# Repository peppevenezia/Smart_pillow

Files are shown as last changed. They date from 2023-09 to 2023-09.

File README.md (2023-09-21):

# Posture Monitoring System - PsoCuscino

This project was developed in collaboration with https://github.com/giovanni6inve , https://github.com/Sebastian-Gerletti , https://github.com/alecac96

## Aim of the project

Sitting posture classifiaction for behavioral analysis of desk workers, in particuar working at PC. Data is collected from 11 FSR sensors (Force Sensitive Resistors) arranged on a chair.

## Hardware and set-up
<figure>

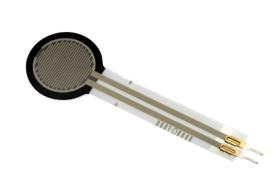
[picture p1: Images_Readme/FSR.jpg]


<figcaption>Force Sensitive Resistor (FSR).</figcaption>

</figure>

FSR sensors (strain gauges) are read by voltage partitioning on a resistance of 10kohm (Rb) and high impedence readout provided by the PSoC.

<figure>

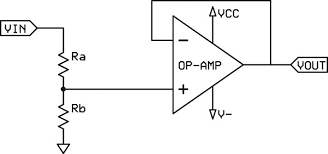
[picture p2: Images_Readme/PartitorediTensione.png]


<figcaption>Vin is 5V alimentation, the variable resistance (FSR) is Ra.</figcaption>

</figure>

The 11 sensors are iteratively read by an AMUX which feeds the analog signal for conversion to the ADC DelSig configured at 16 bit resolution, Multi Sample (since independent sensors) and 10000SPS. The sampling period is of 300ms, set by timer ISR, at which all sensors are read, sampled and sent to the GUI using UART serial communication (baud rate of 115200bps).

For easy and simple interfacing with the user (namely connection research, connected, sampling and calibration) a LED was set using a variable PWM. 

The sensor disposition upon the chair is symmetric w.r.t. the sagittal plane and while maintaining a base disposition as in figure, their precise position was optimized for maximum activation according to physiological pressure points and allowing for interuser variability: namely male/female, height ranges from 154cm to 200cm and weights from 49kg to 93kg.

<figure>

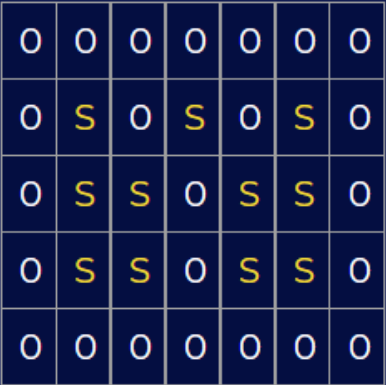
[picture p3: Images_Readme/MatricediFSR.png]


<figcaption>Where "S" stands for the FSR sensor and 0 is for the space on the hard surface, where they are attached to with tape, in between them.</figcaption>

</figure>

## Firmware (PSoC)

Connection between GUI and PSoC is dealt with automatically: the GUI sends "v" by UART, PSoC transmits "Posture$$$" in responce; if this "handshaking" (mutual recognition happens) connecion is confirmed by the GUI: "e" is received.

Once "b" is received all sensors are sampled at 3.33Hz and the 16bit value for each one is unpacked into 2 bytes for serial communication. During the first 4.5s, during which the subject is already seated, the calibration procedure takes place: it is aimed at rescaling all sensors' values by the same factor in order to exploit the whole 16 bit range, the factor is obtained dividing the desired maximum output (65535) by the actual global maximum among the sampled values for all sensors (15 samples * 11 sensors). By doing so a heavy subject and a lighter one will be associated with an equally intense heatmap (considering the values for the higher pressure points).

The synchrony and activation of all this is given by the a timer which is turned on upon "b" receval and off with "s".

## Software (GUI)
(Particular attention was given to interoperability of the whole process among different operating systems).

Upon launching the application, in order to find the port to which the PSoC is connected to, all the list of ports is iterated and the char "v" is sent to each port with a hardcoded baud rate (shared by the PSoC). Ports are passed by if a limit of time spent within them is reached; if "Posture$$$" is received connection is confirmed with that port (PSoC's one) by sending "e" to it.

To then communicate with the device a user-friendly interface is presented: "start" and "stop" buttons, which transmit "b" and "s" respectively; as for visualization, once "start" has been pressed the heatmap given by the sensors' padded and interpolated (upsampled) data is presented; and below the heatmap the posture prediction is written having as classes: "correct", "leaning forwards", "leaning backwards", "leaning right" and "leaning left". Notice the sensors' set-up, should also guarantee the recognition of crossed-legs posture but in order to train a network capable to distinguish between leaning sideways and doing so with crossed legs much more data would have been necessary to obtain satisfying performances since a more complex model would have been necessary to face the more complex task.
#### Data decoding
Each sensor value is kept in 16 bit format, so the heatmap scale goes from 0 to 65535; however since a string of 48 chars containing all sensors' data scopmosed in MSB and LSB (each then composed by 2 chars) is received, the 11 sensors values need to be re-assembled (reverse the shift and masking done at PSoC level) after cropping the head and the tail (each of 2 fixed chars).
#### Interpolation (upsampling)
Plotting only the 11 values which are sampled from the sensors is not sufficient for a clear and interpretable image, for this reason upsampling is required, the best method to replicte true weight distribution proved to be interpolation done using scipy's griddata function and an appropriate padding.

Padding is done, by linealy combining the sensors' values according to the matrix in the figure above and accounting for borders using a multiplicative decay. This was done to space the sensors' positions both from borders and from each other when feeding them to griddata which then performs a much more complex interpolation accounting for the exact positions of sensors (measured on the chair) and custom padding  (approximated from the previous measurements) and exploiting a non linear combination of values. A 41x45 image is thus obtained.

<figure>

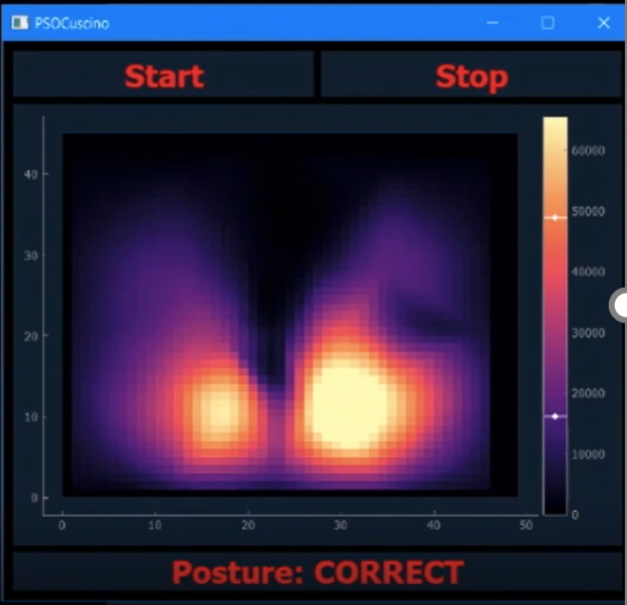
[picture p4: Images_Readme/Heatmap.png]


<figcaption>GUI: buttons, heatmap, class prediction.</figcaption>

</figure>

#### Posture classification
To classify the posture among the aforementioned classes a neural network was implemented. A prediction is provided for each frame (300ms) by inserting the prediction "pipeline" within the iterating thread of the GUI which reads, interpolates and plots data. The pipeling includes data rescaling other than the actual prediction and it does so by using the parameters obtained from the training set to normalize the data and the saved model.

The model to classify each frame is a neural network which was trained,tuned and tested with data from 15 users, split in 2 disjoint and stratified sets (after informed consent signing).

The protocol to acquire the training data, and quite intuitively to label it, was to sample 1min (so 200 samples per position) in each position (after calibration) in the same order reported above.

Notice: for the model training a few considerations must be made regarding the replicability of our procedure:\
as regards data acquisitions for the training dataset (done with the above protocol) once "stop" has been pressed on the GUI the "export file" button is available and it automatically saves the User's data (name of the user to be specified when running the application from terminal where, if no data for that user has already been obtained, the corresponding folder is created) at a path related to where the code is run from, for this reason coherence in the path explicitaded in posture_net.py, when loading the data, is required.

Furthermore the data we collected is not uploaded in the repository for privacy reasons.
Regardless of this the pretrained model is uploaded for online application on new data.

<figure>

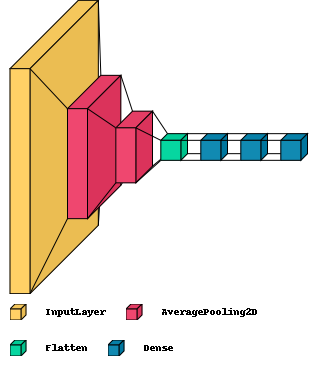
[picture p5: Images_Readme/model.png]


<figcaption>Model's architecture: average pooling from 41x45 (input) to 20x22; average pooling to 10x11 (similar to local baricenters extraction with decreasing resolution); flatten; dense layers (100 - 50 - 5) where the last layer has softmax activation to obtain the output probabilities of the 5 classes.</figcaption>

</figure>

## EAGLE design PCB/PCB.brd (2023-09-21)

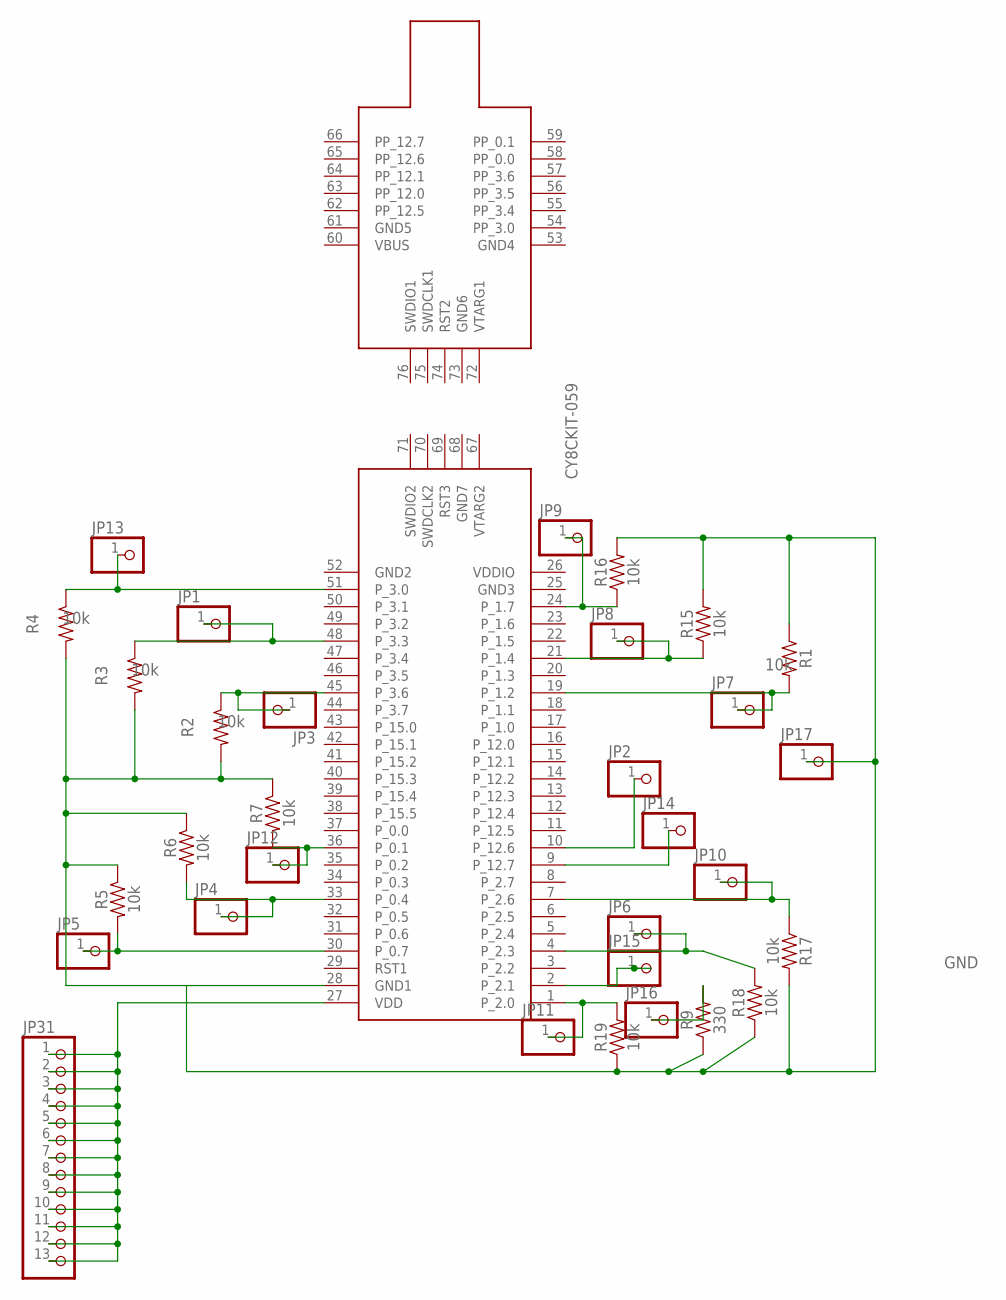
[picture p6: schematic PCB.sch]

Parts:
JP1, JP2, JP3, JP4, JP5, JP6, JP7, JP8, JP9, JP10, JP11, JP12, JP13, JP14, JP15, JP16, JP17: PINHD-1X1; 1X01
JP31: PINHD-1X13; 1X13
R1, R2, R3, R4, R5, R6, R7, R15, R16, R17, R18, R19: 10k; AXIAL-0.3
R9: 330; AXIAL-0.3
U$1: CY8CKIT-059

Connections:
GND: JP17.1, R1.P$1 (1), R2.P$2 (2), R3.P$2 (2), R4.P$2 (2), R5.P$1 (1), R6.P$1 (1), R7.P$1 (1), R9.P$1 (1), R15.P$2 (2), R16.P$2 (2), R17.P$2 (2), R18.P$1 (1), R19.P$1 (1), U$1.28 (GND1)
unnamed: JP3.1, R2.P$1 (1), U$1.45 (P_3.6)
unnamed: JP4.1, R6.P$2 (2), U$1.33 (P_0.4)
unnamed: JP12.1, R7.P$2 (2), U$1.36 (P_0.1)
unnamed: JP5.1, R5.P$2 (2), U$1.30 (P_0.7)
unnamed: JP1.1, R3.P$1 (1), U$1.48 (P_3.3)
unnamed: JP9.1, R16.P$1 (1), U$1.24 (P_1.7)
unnamed: JP8.1, R15.P$1 (1), U$1.21 (P_1.4)
unnamed: JP7.1, R1.P$2 (2), U$1.19 (P_1.2)
unnamed: JP13.1, R4.P$1 (1), U$1.51 (P_3.0)
unnamed: JP11.1, R19.P$2 (2), U$1.1 (P_2.0)
unnamed: JP6.1, R18.P$2 (2), U$1.4 (P_2.3)
unnamed: JP10.1, R17.P$1 (1), U$1.7 (P_2.6)
unnamed: JP2.1, U$1.10 (P_12.6)
unnamed: JP15.1, U$1.2 (P_2.1)
unnamed: JP16.1, R9.P$2 (2)
unnamed: JP14.1, U$1.9 (P_12.7)
unnamed: JP31.1, JP31.2, JP31.3, JP31.4, JP31.5, JP31.6, JP31.7, JP31.8, JP31.9, JP31.10, JP31.11, JP31.12, JP31.13, U$1.27 (VDD)

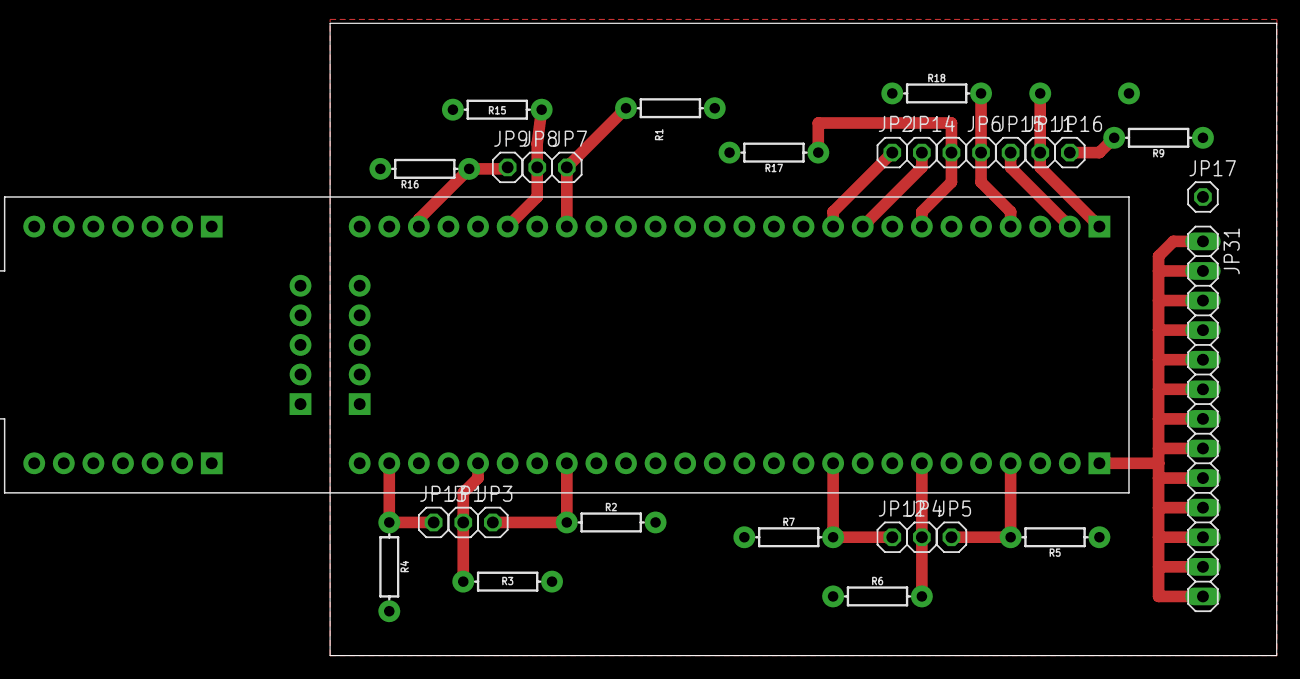
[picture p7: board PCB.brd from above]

Board: 2 copper layers, 81.3 x 54.3 mm, 32 parts (1 on the bottom side), 18 nets.

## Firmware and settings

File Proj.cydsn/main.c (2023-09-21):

/* ========================================
 *
 * Copyright YOUR COMPANY, THE YEAR
 * All Rights Reserved
 * UNPUBLISHED, LICENSED SOFTWARE.
 *
 * CONFIDENTIAL AND PROPRIETARY INFORMATION
 * WHICH IS THE PROPERTY OF your company.
 *
 * ========================================
*/
#include "project.h"
#include "InterruptRoutines.h"
#define Nsensors 11
#define BYTES_TO_SEND 2*Nsensors
#define TRANSMIT_BUFFER_SIZE 1+BYTES_TO_SEND+1
uint8 DataBuffer[TRANSMIT_BUFFER_SIZE]={0};
uint8 flag_lettura=0;
//uint8 flag_send=0;
int32 value,max=1;
float gain=1;
uint8 flag_calibr=1, flag_EOCalibr=0;

extern uint8 count, flag_count;
int main(void)
{
    CyGlobalIntEnable; /* Enable global interrupts. */

    PWM_LED_Start();
    PWM_LED_WritePeriod(255); //slow blinking (search for connection)
    PWM_LED_WriteCompare(128);
    
    AMux_Start();
    ADC_DelSig_Start();
    UART_BT_Start();
    isr_RX_StartEx(Custom_ISR_RX);
    isr_ADC_StartEx(Custom_ISR_ADC);
    
    //for (int j=1; j<=BYTES_TO_SEND;j++){
    //    DataBuffer[j]=0;    
    //}
    
    DataBuffer[0]=0xA0;
    DataBuffer[TRANSMIT_BUFFER_SIZE-1]=0xC0;
    
    for(;;)
    {
        
        if (flag_count==1 && flag_calibr==1) { //enters initially but continues only when the timers is started (by receiving "b")
            count++;
            flag_count=0;//to not count more times within the ISR
        }    
        
        if (flag_EOCalibr==1){
            gain=(65535.0)/max; //accounts for users having different weights, the sensors are always sensitive enough but the heatmap and the classification model should be invariant to user's weight offset so this is resolved already at level of passed data 
            flag_EOCalibr=0;
            //flag_calibr=0;
            max=1;
            PWM_LED_WritePeriod(64);  //change blinking to signal EOCalibration
            PWM_LED_WriteCompare(32);
            
            //flag_send=1;
        }
        
        
        if (flag_lettura ==1){
            for (int i=1; i<=Nsensors; i++){
                AMux_FastSelect(i-1);
                value=ADC_DelSig_Read32();
                if (gain<1) gain=1;
                value=value*gain;
                if (value>=65535) value=65535; //65534 
                if (value<0) value=0;
                if (value>max && flag_calibr==1) max=value;
                DataBuffer[2*i-1]= value >> 8; //MSB
                DataBuffer[2*i]= value & 0xff; //LSB
            }
            flag_lettura=0;
            //if (flag_send==1) { //to not send data during calibration
                UART_BT_PutArray(DataBuffer, TRANSMIT_BUFFER_SIZE);
            //}
        }
        
        
    }
}

/* [] END OF FILE */

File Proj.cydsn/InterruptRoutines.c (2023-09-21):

/* ========================================
 *
 * Copyright YOUR COMPANY, THE YEAR
 * All Rights Reserved
 * UNPUBLISHED, LICENSED SOFTWARE.
 *
 * CONFIDENTIAL AND PROPRIETARY INFORMATION
 * WHICH IS THE PROPERTY OF your company.
 *
 * ========================================
*/
#include "project.h"
#include "InterruptRoutines.h"
uint8 ch_received,flag_connected=0;
extern uint8 flag_lettura;
uint8 count=0; 
extern float gain;
extern uint8 flag_calibr,flag_EOCalibr;
uint8 flag_count=1; 
 //after looking at the signal decide weather to do LP filter (start by sampling more frequently and avg for each sensor)
CY_ISR(Custom_ISR_RX){
    ch_received=UART_BT_GetChar();
    switch (ch_received){
        case 'b': //begin sampling and streaming
        case 'B':
            if (flag_connected==1){
                Timer_ADC_Start();
                PWM_LED_WritePeriod(32); //fast blinking (sampling and streaming)
                PWM_LED_WriteCompare(16);
                flag_calibr=1;
                gain=1;
            }
            else {
                PWM_LED_WritePeriod(255); //in case start is requested before connection (LED blinks slowly)
                PWM_LED_WriteCompare(128);   
            }
            
            break;
        
        case 's': //stop sampling and streaming
        case 'S':
            Timer_ADC_Stop();
            if (flag_connected==0){
                PWM_LED_WritePeriod(255); //in case stop is requested before connection (LED blinks slowly)
                PWM_LED_WriteCompare(128);   
            }
            else {
                PWM_LED_WritePeriod(255); //LED ON (connection is still established)
                PWM_LED_WriteCompare(255);
            }    
            break;
        
        case 'v': //search for correct port
            UART_BT_PutString("Posture$$$"); //GUI tries sending v to all connected ports and initializes communication only with the one which replies like this
            break;

        case 'e': //GUI sends e once it receives Posture$$$ and is ready to receive data
            PWM_LED_WritePeriod(255); //LED ON (conection established)
            PWM_LED_WriteCompare(255);
            flag_connected=1;
            break;  

    }

}


CY_ISR(Custom_ISR_ADC){
    Timer_ADC_ReadStatusRegister();

    flag_lettura=1; //at each ISR send signal to sample all sensors (done outside ISR in order not to block it)
    
    //flag_count=1; 
    if (flag_calibr==1) { //for calibration time window
        flag_count=1;
    }
    if(count==15) {//15 for 4,5 s or 33 9.9 seconds with ISR period of 300ms
        count=0;
        flag_calibr=0;
        flag_EOCalibr=1;
    }
}
/* [] END OF FILE */

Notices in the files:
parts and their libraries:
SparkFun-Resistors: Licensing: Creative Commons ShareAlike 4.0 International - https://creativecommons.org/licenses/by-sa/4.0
